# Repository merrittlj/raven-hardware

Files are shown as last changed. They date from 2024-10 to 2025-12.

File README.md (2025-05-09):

<h1 align="center">
    <br>
    Raven - Hardware Repository
    <br>
</h1>
<p align="center">
    
    
    
</p>

## About
This is the hardware repository for the Raven smartwatch. Versioning is completely independent of the firmware repository.

## License

Distributed under the GPLv3. See ['LICENSE'](LICENSE) for more info.

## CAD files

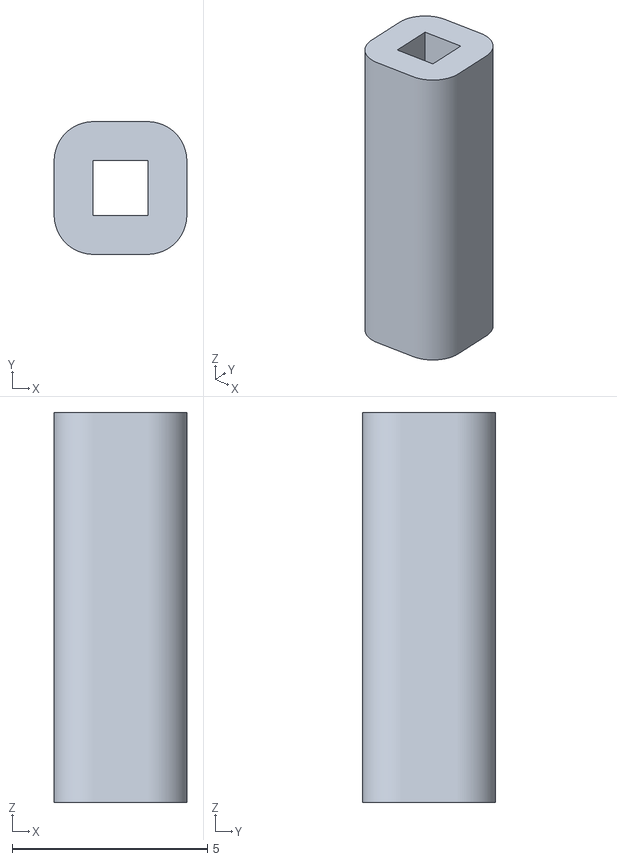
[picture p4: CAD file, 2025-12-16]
case/build.stl
3.40 x 3.40 x 10.0

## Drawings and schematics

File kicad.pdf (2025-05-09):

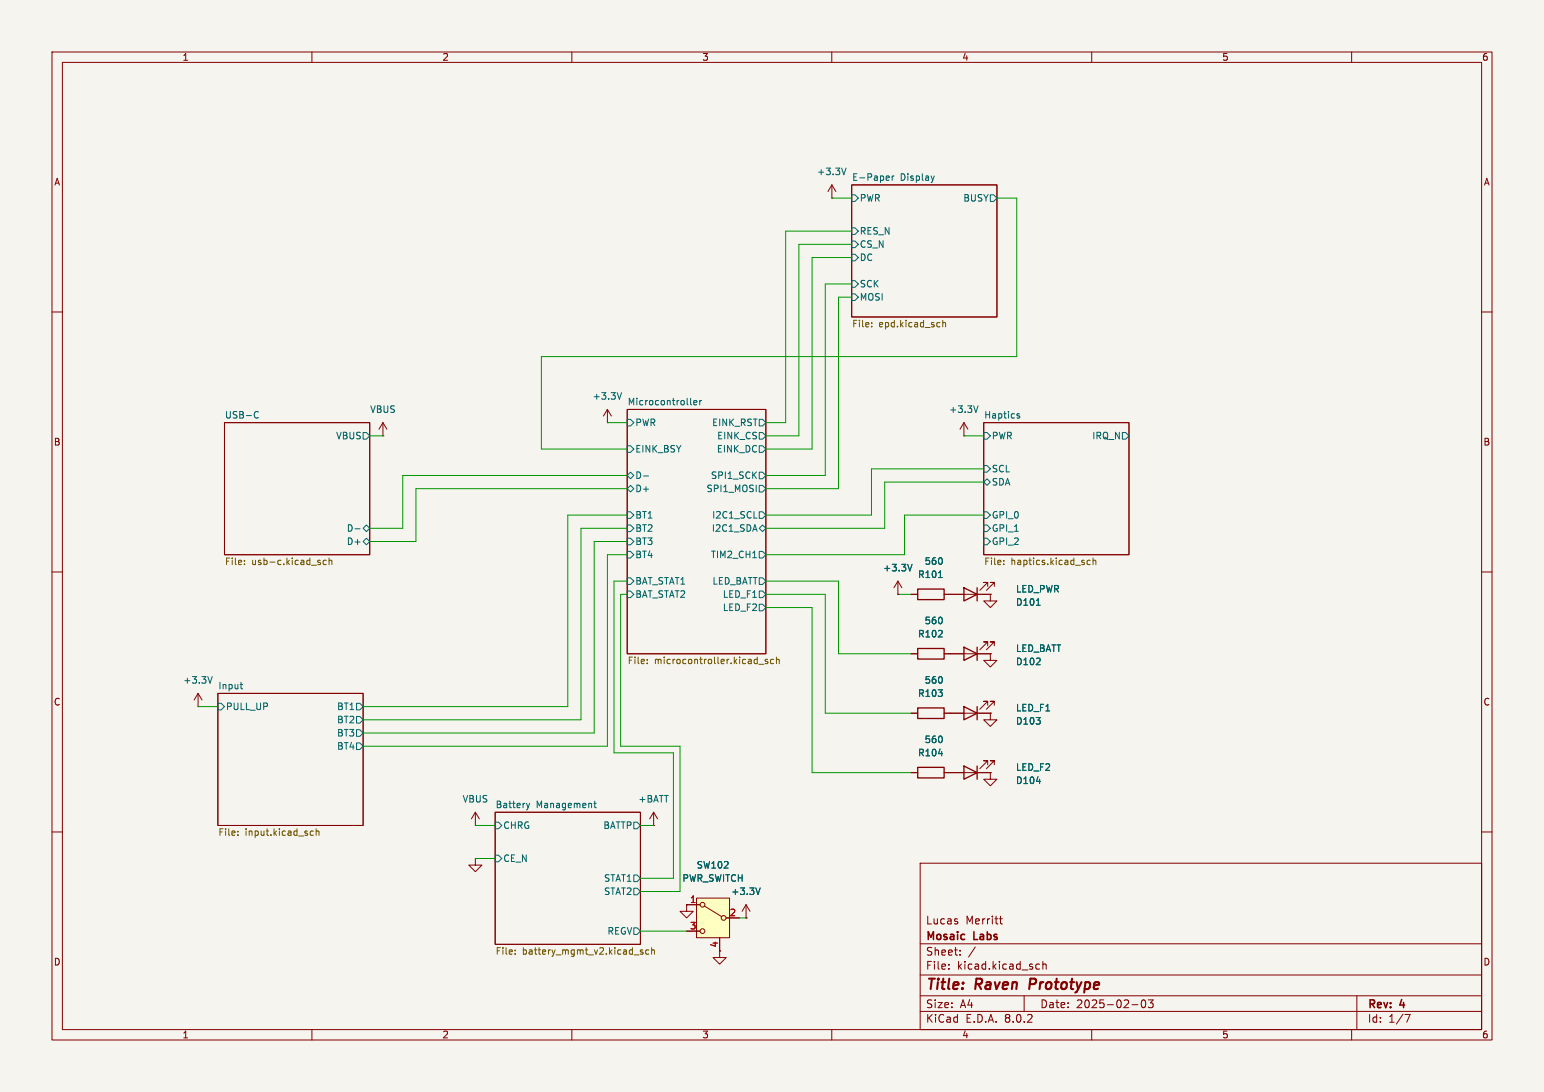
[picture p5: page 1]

SDA Haptics File: haptics.kicad_sch +3.3V

Id: 1/7 Title: Raven Prototype

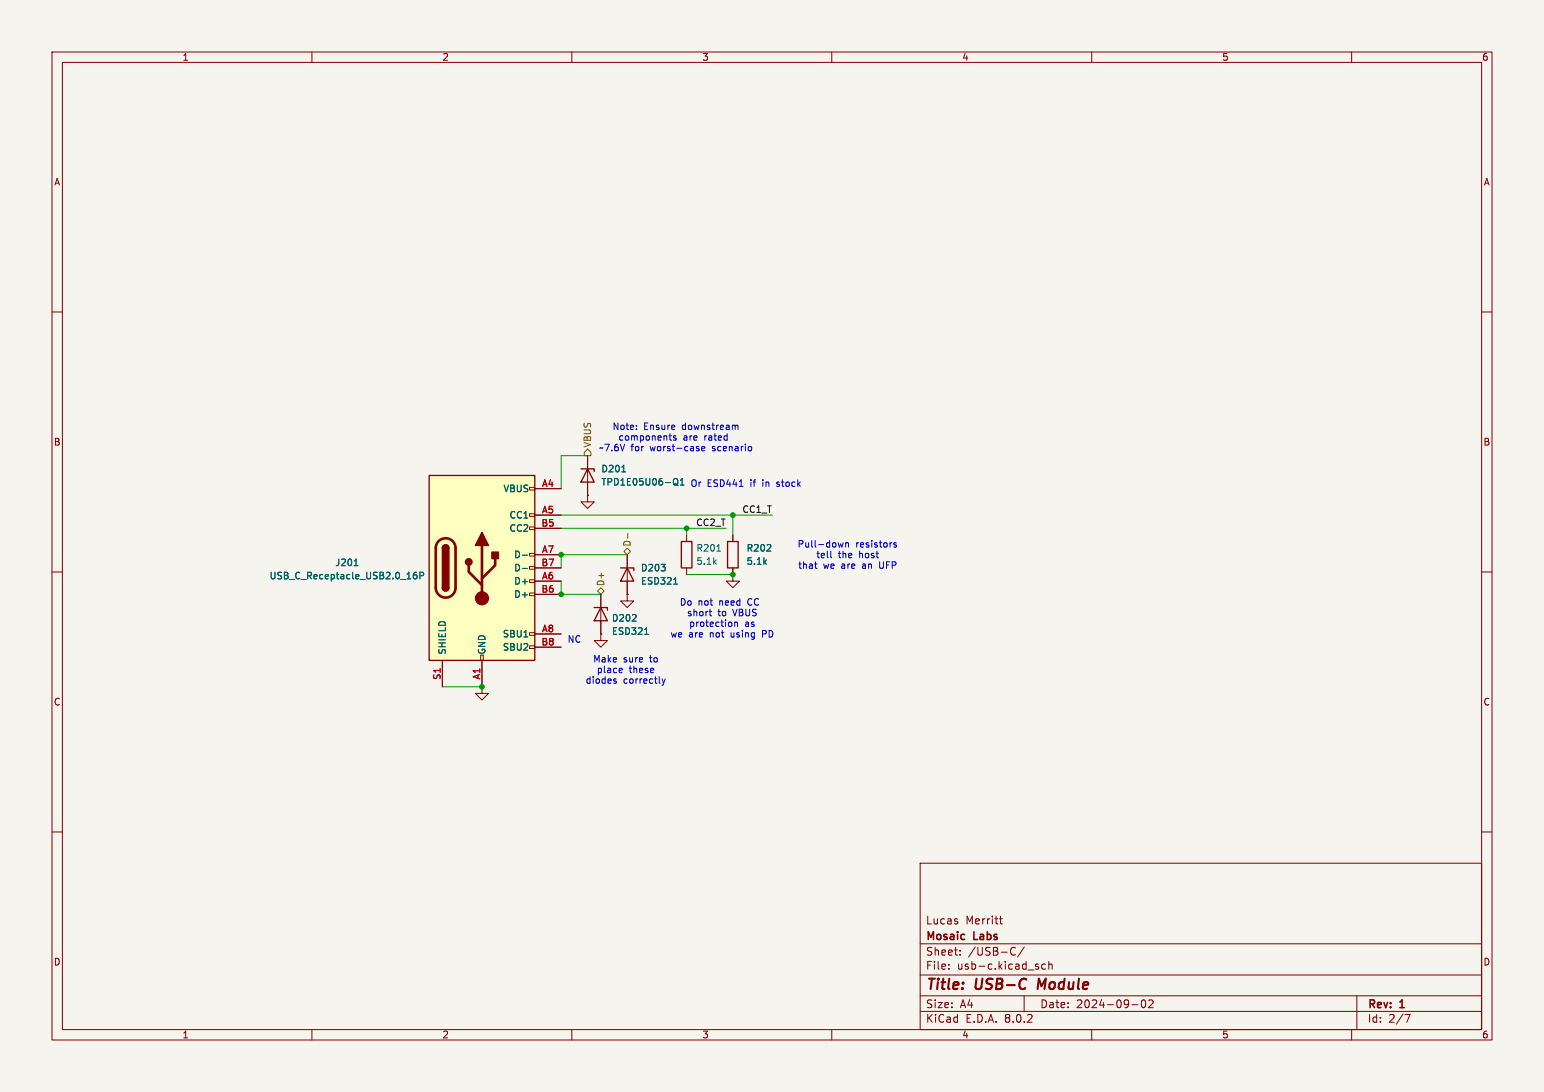
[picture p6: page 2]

Id: 2/7 Title: USB-C Module

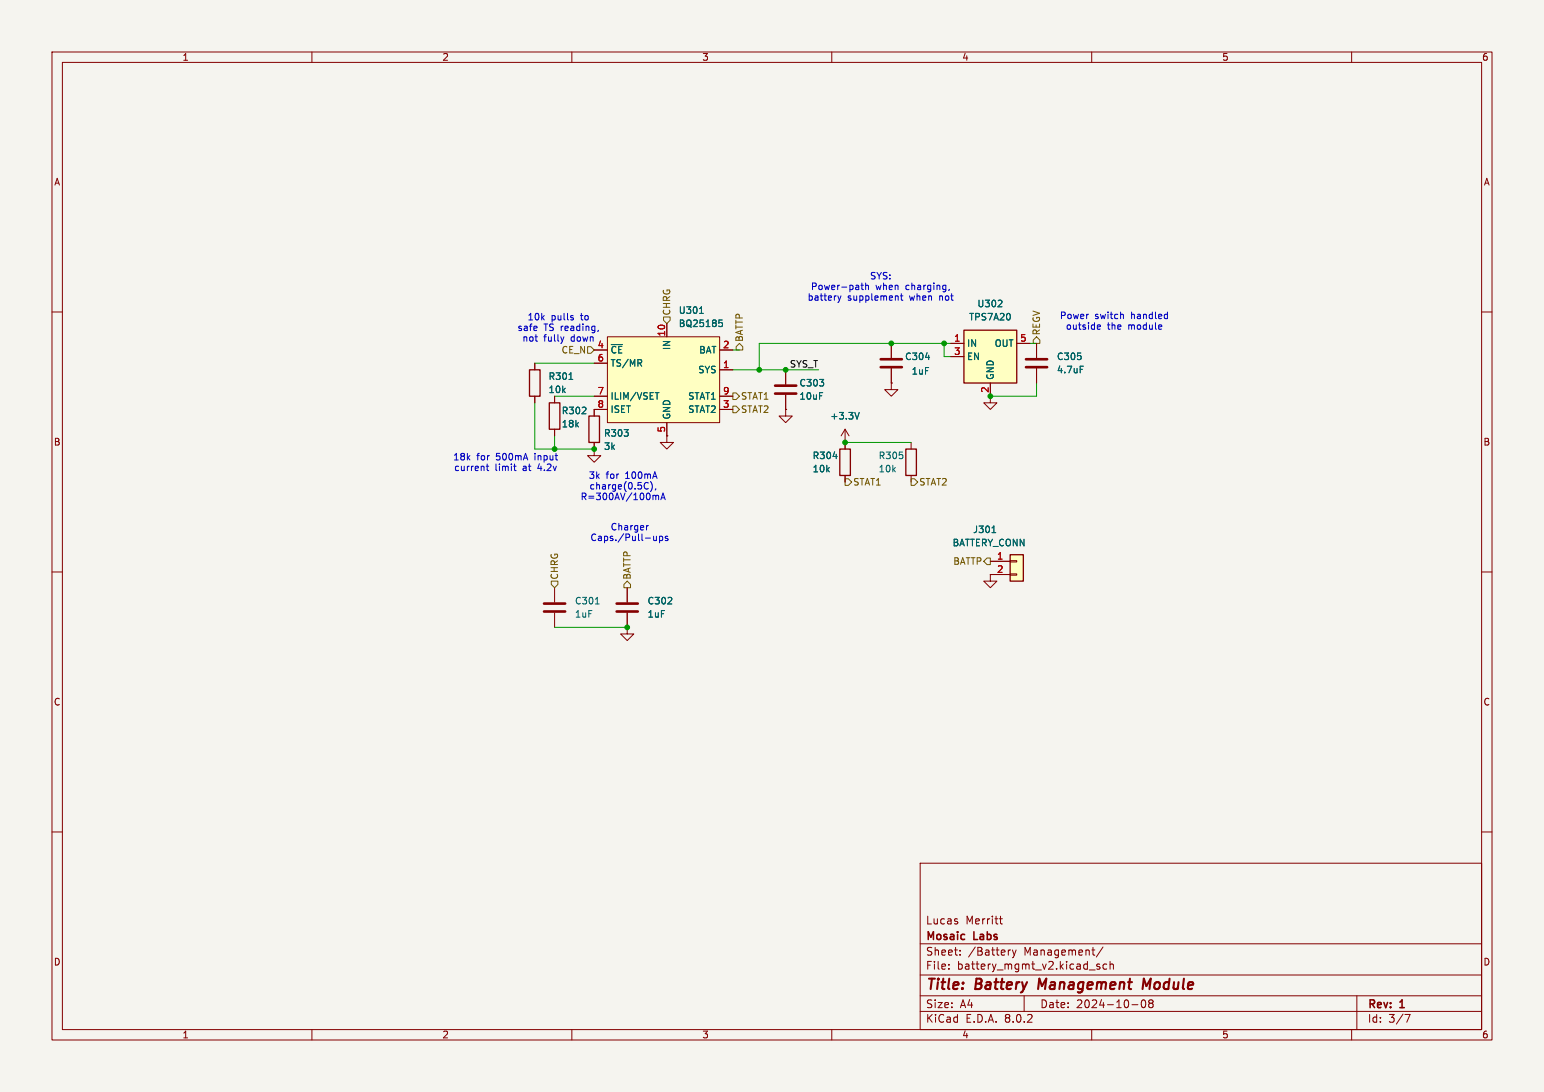
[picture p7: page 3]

2 EN 3 OUT 5 U302 TPS7A20 SYS 1 IN 10 BAT 2 STAT2 3 ~{CE} 4 GND
outside the module Charger

Caps./Pull-ups 3k for 100mA

Id: 3/7 Title: Battery Management Module

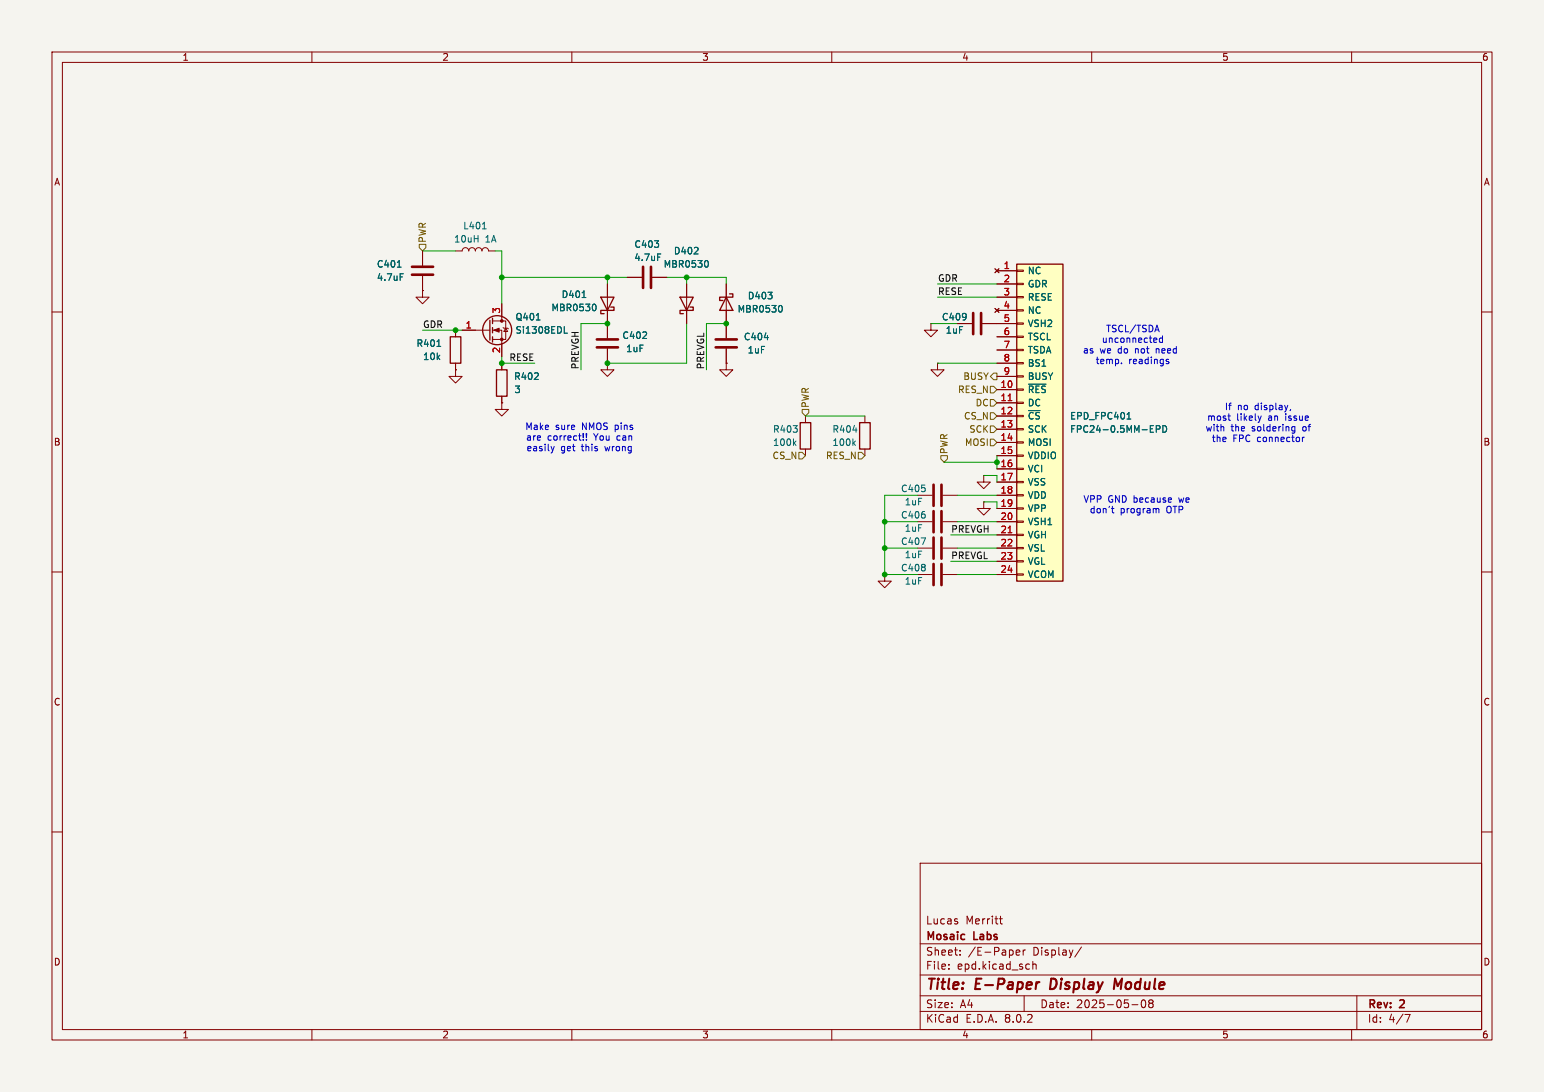
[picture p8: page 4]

easily get this wrong D401 MBR0530 C401

the FPC connector TSCL/TSDA
unconnected
as we do not need

VPP GND because we
don't program OTP

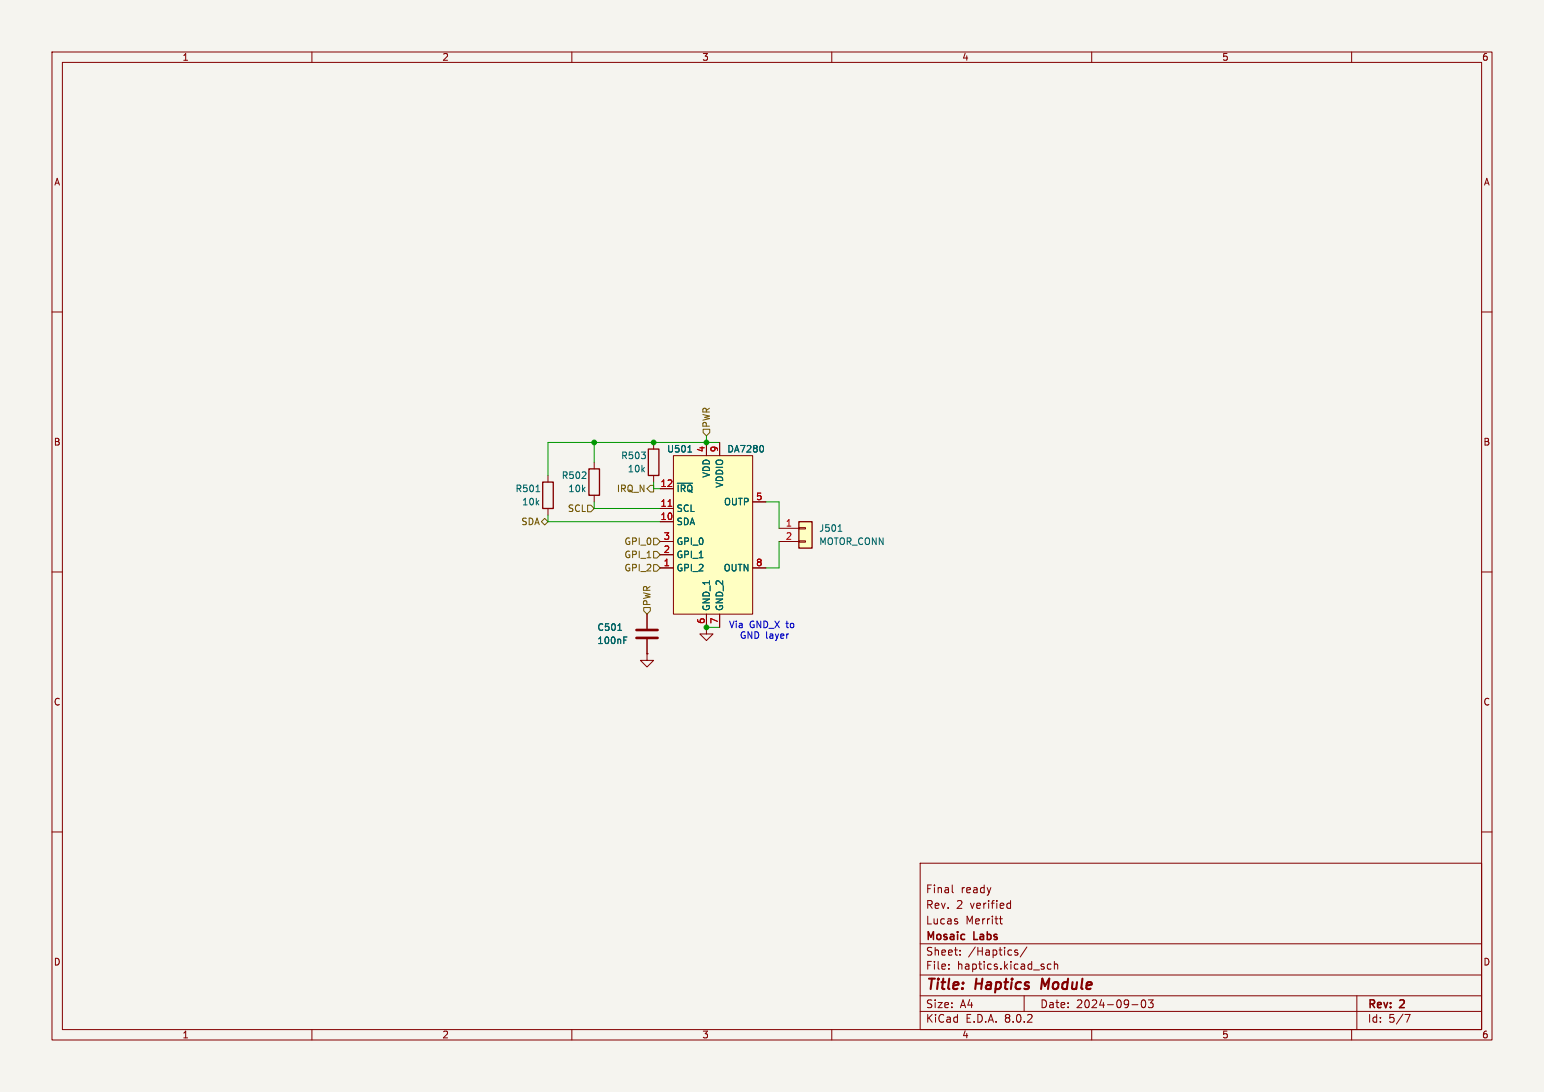
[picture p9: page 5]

Id: 5/7 Title: Haptics Module

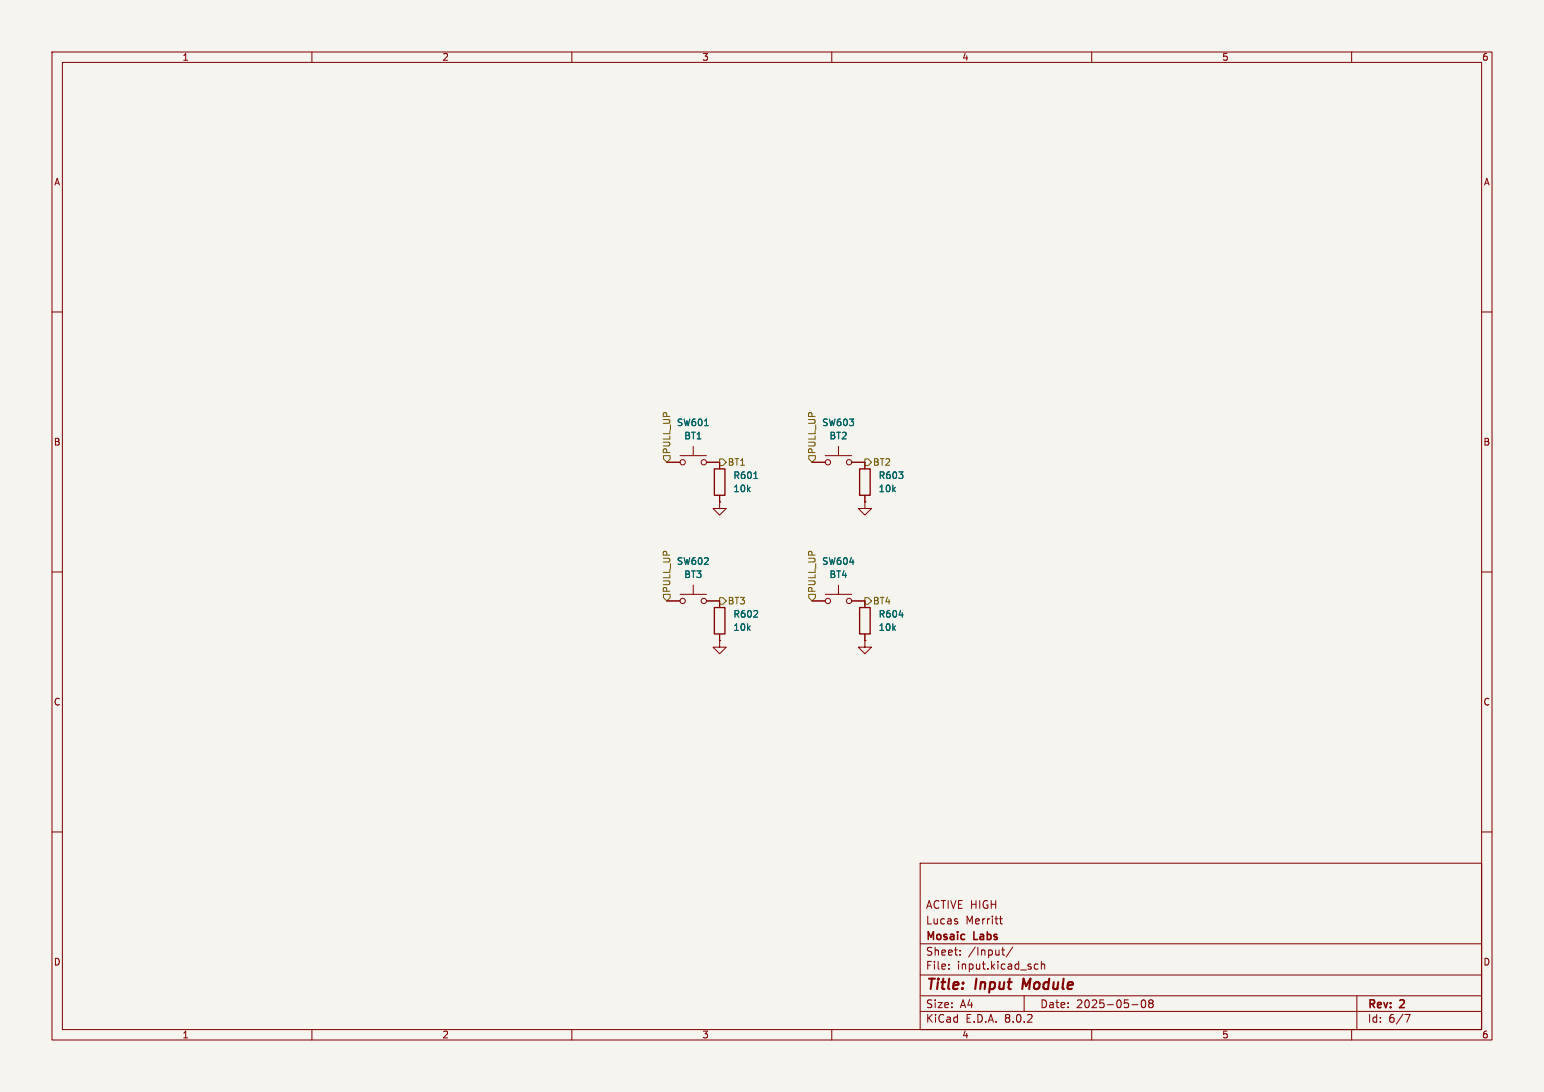
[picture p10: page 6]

Id: 6/7 Title: Input Module

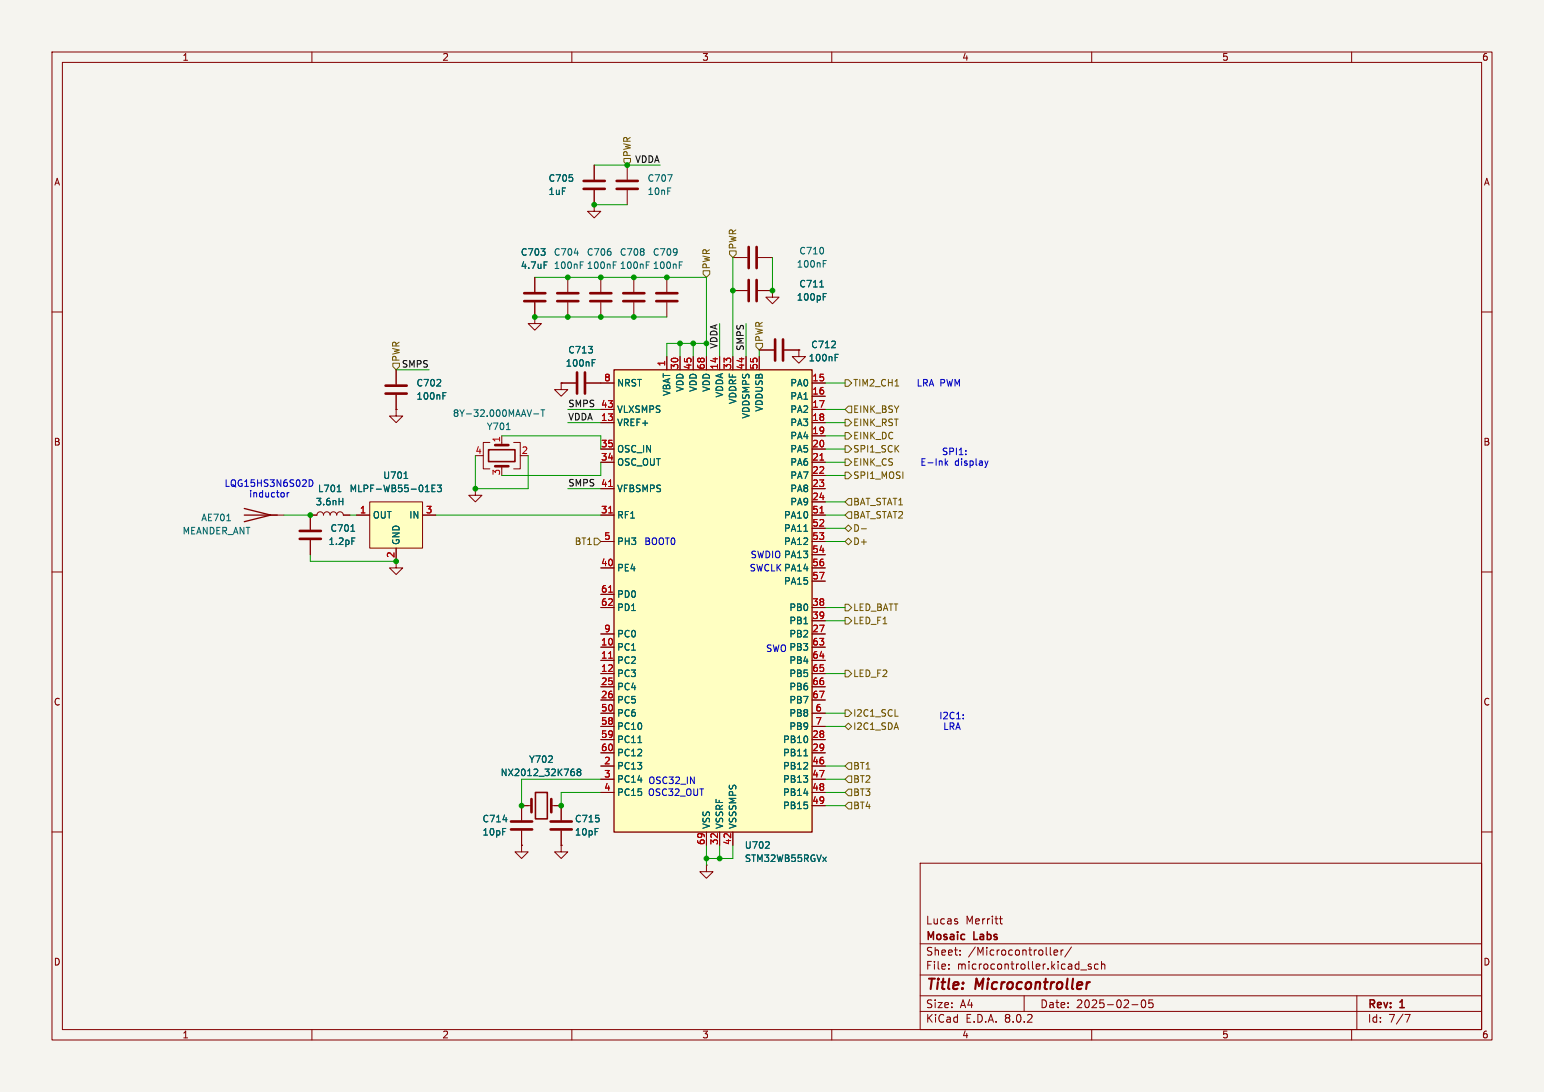
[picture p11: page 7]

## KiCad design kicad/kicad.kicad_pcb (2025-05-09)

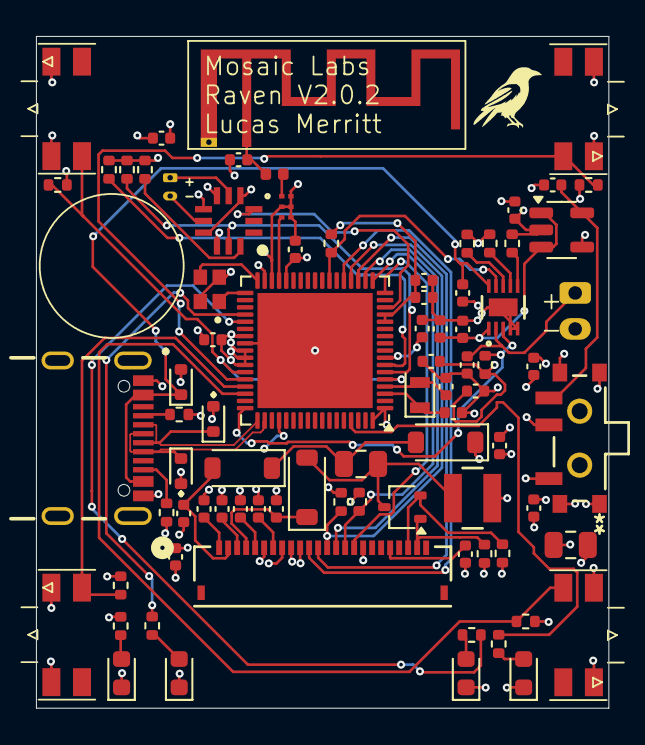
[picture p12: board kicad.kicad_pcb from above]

Board: 4 copper layers, 31.8 x 37.3 mm, 82 parts (0 on the bottom side), 57 nets.

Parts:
AE701: MEANDER_ANT; Texas_SWRA117D_2.4GHz_Right
C301, C302, C304, C402, C404, C405, C406, C407, C408, C409, C705: 1uF; C_0402_1005Metric
C303: 10uF; C_0402_1005Metric
C305, C703: 4.7uF; C_0402_1005Metric
C401, C403: 4.7uF; C_0805_2012Metric
C501, C702, C704, C706, C708, C709, C710, C712, C713: 100nF; C_0402_1005Metric
C701: 1.2pF; C_0402_1005Metric
C707: 10nF; C_0402_1005Metric
C711: 100pF; C_0402_1005Metric
C714, C715: 10pF; C_0402_1005Metric
D101: LED_PWR; D_0603_1608Metric
D102: LED_BATT; D_0603_1608Metric
D103: LED_F1; D_0603_1608Metric
D104: LED_F2; D_0603_1608Metric
D201: TPD1E05U06-Q1; D_SOD-523
D202, D203: ESD321; D_SOD-523
D401, D402, D403: MBR0530; D_SOD-123
EPD_FPC401: FPC24-0.5MM-EPD; CONN_F3311A7H121024E200_AMP_FACE_UP
J201: USB_C_Receptacle_USB2.0_16P; GCT_USB4105-GF-A-16P
J301: BATTERY_CONN; CUSTOM_BATT_CONN
J501: MOTOR_CONN; CUSTOM_MOTOR_CONN
L401: 10uH 1A; IND_BOURNS_SRN3015
L701: 3.6nH; L_0402_1005Metric
Q401: Si1308EDL; SOT-323_SC-70
R101, R102, R103, R104: 560; R_0402_1005Metric
R201, R202: 5.1k; R_0402_1005Metric
R301, R304, R305, R401, R501, R502, R503, R601, R602, R603, R604: 10k; R_0402_1005Metric
R302: 18k; R_0402_1005Metric
R303: 3k; R_0402_1005Metric
R402: 3; R_0402_1005Metric
R403, R404: 100k; R_0402_1005Metric
SW102: PWR_SWITCH; SSSS811101
SW601: BT1; EVQPUA
SW602: BT3; EVQPUA
SW603: BT2; EVQPUA
SW604: BT4; EVQPUA
U301: BQ25185; WSON10_DLH_TEX-M
U302: TPS7A20; SOT-23-5
U501: DA7280; QFN-12-3x3mm-P0.65mm
U701: MLPF-WB55-01E3
U702: STM32WB55RGVx; QFN-68-1EP_8x8mm_P0.4mm_EP6.4x6.4mm
Y701: 8Y-32.000MAAV-T; XTAL_ECS-160-9-37-CKM-TR
Y702: NX2012_32K768; Crystal_SMD_2012-2Pin_2.0x1.2mm

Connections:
+3.3V: C401.1, C501.1, C702.1, C703.1, C704.1, C705.1, C706.1, C707.1, C708.1, C709.1, C710.1, C711.1, C712.2, EPD_FPC401.15 (VDDIO), EPD_FPC401.16 (VCI), L401.2, R101.1, R304.1, R305.1, R403.1, R404.1, R501.1, R502.1, R503.1, SW102.2 (B), SW601.1, SW602.1, SW603.1, SW604.1, U501.4 (VDD), U501.9 (VDDIO), U702.1 (VBAT), U702.13 (VREF+), U702.14 (VDDA), U702.30 (VDD), U702.33 (VDDRF), U702.41 (VFBSMPS), U702.43 (VLXSMPS), U702.44 (VDDSMPS), U702.45 (VDD), U702.55 (VDDUSB), U702.68 (VDD)
+BATT: C302.1, J301.1, U301.2 (BAT)
/Battery Management/REGV: C305.1, SW102.3 (C), U302.5 (OUT)
/Battery Management/STAT1: R304.2, U301.9 (STAT1), U702.24 (PA9)
/Battery Management/STAT2: R305.2, U301.3 (STAT2), U702.51 (PA10)
/Battery Management/SYS_T: C303.1, C304.1, U301.1 (SYS), U302.1 (IN), U302.3 (EN)
/E-Paper Display/BUSY: EPD_FPC401.9 (BUSY), U702.17 (PA2)
/E-Paper Display/CS_N: EPD_FPC401.12 (~CS), R403.2, U702.21 (PA6)
/E-Paper Display/DC: EPD_FPC401.11 (DC), U702.19 (PA4)
/E-Paper Display/GDR: EPD_FPC401.2 (GDR), Q401.1 (G), R401.2
/E-Paper Display/MOSI: EPD_FPC401.14 (MOSI), U702.22 (PA7)
/E-Paper Display/PREVGH: C402.2, D401.1 (K), EPD_FPC401.21 (VGH)
/E-Paper Display/PREVGL: C404.2, D403.2 (A), EPD_FPC401.23 (VGL)
/E-Paper Display/RESE: EPD_FPC401.3 (RESE), Q401.2 (S), R402.1
/E-Paper Display/RES_N: EPD_FPC401.10 (~RES), R404.2, U702.18 (PA3)
/E-Paper Display/SCK: EPD_FPC401.13 (SCK), U702.20 (PA5)
/Haptics/GPI_0: U501.3 (GPI_0), U702.15 (PA0)
/Haptics/IRQ_N: R503.2, U501.12 (~IRQ)
/Haptics/SCL: R502.2, U501.11 (SCL), U702.6 (PB8)
/Haptics/SDA: R501.2, U501.10 (SDA), U702.7 (PB9)
/Input/BT1: R601.1, SW601.2, U702.5 (PH3), U702.46 (PB12)
/Input/BT2: R603.1, SW603.2, U702.47 (PB13)
/Input/BT3: R602.1, SW602.2, U702.48 (PB14)
/Input/BT4: R604.1, SW604.2, U702.49 (PB15)
/Microcontroller/D+: D202.1 (K), J201.A6 (D+), J201.B6 (D+), U702.53 (PA12)
/Microcontroller/D-: D203.1 (K), J201.A7 (D-), J201.B7 (D-), U702.52 (PA11)
/Microcontroller/LED_BATT: R102.1, U702.38 (PB0)
/Microcontroller/LED_F1: R103.1, U702.39 (PB1)
/Microcontroller/LED_F2: R104.1, U702.65 (PB5)
/USB-C/CC1_T: J201.A5 (CC1), R202.1
/USB-C/CC2_T: J201.B5 (CC2), R201.1
GND: C301.2, C302.2, C303.2, C304.2, C305.2, C401.2, C402.1, C404.1, C405.1, C406.1, C407.1, C408.1, C409.1, C501.2, C701.2, C702.2, C703.2, C704.2, C705.2, C706.2, C707.2, C708.2, C709.2, C710.2, C711.2, C712.1, C713.1, C714.2, C715.2, D101.1 (K), D102.1 (K), D103.1 (K), D104.1 (K), D201.2 (A), D202.2 (A), D203.2 (A), D402.1 (K), EPD_FPC401.8 (BS1), EPD_FPC401.17 (VSS), EPD_FPC401.19 (VPP), J201.A1 (GND), J201.A12 (GND), J201.B1 (GND), J201.B12 (GND), J201.S1 (SHIELD), J301.2, R201.2, R202.2, R301.2, R302.2, R303.2, R401.1, R402.2, R601.2, R602.2, R603.2, R604.2, SW102.1 (A), SW102.4, U301.4 (~CE), U301.5 (GND), U301.11 (NC), U302.2 (GND), U302.4 (NC), U501.6 (GND_1), U501.7 (GND_2), U701.2 (GND), U701.4 (GND), U701.5 (GND), U701.6 (GND), U702.32 (VSSRF), U702.42 (VSSSMPS), U702.69 (VSS), Y701.2, Y701.4
unnamed: AE701.1 (A), C701.1, L701.1
unnamed: D101.2 (A), R101.2
unnamed: D102.2 (A), R102.2
unnamed: D103.2 (A), R103.2
unnamed: D104.2 (A), R104.2
unnamed: C403.1, D401.2 (A), L401.1, Q401.3 (D)
unnamed: C403.2, D402.2 (A), D403.1 (K)
unnamed: C408.2, EPD_FPC401.24 (VCOM)
unnamed: C405.2, EPD_FPC401.18 (VDD)
unnamed: C406.2, EPD_FPC401.20 (VSH1)
unnamed: C409.2, EPD_FPC401.5 (VSH2)
unnamed: C407.2, EPD_FPC401.22 (VSL)
unnamed: J501.1, U501.5 (OUTP)
unnamed: J501.2, U501.8 (OUTN)
unnamed: R302.1, U301.7 (ILIM/VSET)
unnamed: R303.1, U301.8 (ISET)
unnamed: R301.1, U301.6 (TS/MR)
unnamed: U701.3 (IN), U702.31 (RF1)
unnamed: L701.2, U701.1 (OUT)
unnamed: C713.2, U702.8 (NRST)
unnamed: U702.35 (OSC_IN), Y701.1
unnamed: U702.34 (OSC_OUT), Y701.3
unnamed: C714.1, U702.3 (PC14), Y702.1
unnamed: C715.1, U702.4 (PC15), Y702.2
VBUS: C301.1, D201.1 (K), J201.A4 (VBUS), J201.A9 (VBUS), J201.B4 (VBUS), J201.B9 (VBUS), U301.10 (IN)

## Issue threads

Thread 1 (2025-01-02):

EPD display not showing anything

merrittlj, 2025-01-02:
This is a complex bug, but it mainly originates from the improper boost converter. The SPI communication seems to be working entirely fine, it just is not getting enough power to actually display the image it wants to.

I believe this originates from the incorrect MOSFET pins, which are fixed in Rev. 2, but I have yet to test this.

merrittlj, 2025-01-10:
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
Wow... Not only does the hacky soldering job work but it was simply the MOSFET...

Closed 2025-01-10.

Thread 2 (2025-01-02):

LEDs way too bright

merrittlj, 2025-01-02:
The LEDs were designed by using the voltages reccomended under the ideal operating conditions on the datasheet, but who ever chose these conditions made them blindingly bright, we need to add much larger resistors.

Resistors in the 1-3k range seem to work nice.

merrittlj, 2025-01-10:
Completed by d8ea87978131bd46c603eb13500808e90a7d5579

Closed 2025-01-10.

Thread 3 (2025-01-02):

FPC connector issues

merrittlj, 2025-01-02:
The FPC connector(https://www.digikey.com/short/9n5nj2th) is currently out of stock and slightly problematic. The FPC cable does not fully go in to a satisfying/assuring degree, but as long as the display circuit is properly verified this might be fine. Additionally, we do not need connections on both sides of the connector.

merrittlj, 2025-01-10:
Display is verified, FPC works fine, but still need to switch out connector(maybe? there are some equivalents).

merrittlj, 2025-01-10:
Completed by d8ea87978131bd46c603eb13500808e90a7d5579

Closed 2025-01-10.

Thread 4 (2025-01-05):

Power on and off management

merrittlj, 2025-01-05:
How should the hardware handle powering the device on and off? Is such a feature necessary, what is the complexity of doing such, etc.

merrittlj, 2025-02-07:
This was completed a while ago with the addition of a physical power switch.

Closed 2025-02-07.

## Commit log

2024-08-16 start adding connectors
    [kicad.kicad_pcb, kicad.kicad_sch]
2024-08-17 connect all fpc connector pins
    [kicad.kicad_sch]
2024-08-17 first boost converter revision
    [kicad.kicad_sch]
2024-08-18 schem v1
    [kicad.kicad_sch]
2024-08-22 add debugging to v1
    [kicad.kicad_sch]
2024-08-23 add DA7280 symbol, rename to raven, organize schem
    [kicad.kicad_sch]
2024-08-24 reorganize schematic, add haptic, debug, connector module
    [kicad.kicad_sch]
2024-08-25 start power circuit
    [kicad.kicad_sch]
2024-08-25 power IC work
    [kicad.kicad_sch]
2024-08-26 reorganize, start usb-c
    [kicad.kicad_sch]
2024-08-28 start usb-c symbols
    [kicad.kicad_sch]
2024-08-28 finish usb esd symbol
    [kicad.kicad_sch]
2024-08-29 power close to completion
    [kicad.kicad_sch]
2024-08-31 add BQ21061
    [kicad.kicad_sch, power_supply.kicad_sch]
2024-09-03 modularize usb-c
    [kicad.kicad_sch, usb-c.kicad_sch, usbc_power.kicad_sch]
2024-09-04 add datasheets, modularize current hardware
    [battery_management.kicad_sch, battery_mgmt.kicad_sch, epd.kicad_sch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]
2024-09-10 add power v2, input, storage modules
    [battery_mgmt_v1.kicad_sch, battery_mgmt_v2.kicad_sch, input.kicad_sch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]
2024-09-11 refactor, fix issues, ready for first design
    [battery_management.kicad_sch, battery_mgmt.kicad_sch, battery_mgmt_v2.kicad_sch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]
2024-09-19 sync, almost done
    [kicad.kicad_sch]
2024-09-28 schematic should be finished
    [battery_mgmt_v2.kicad_sch, epd.kicad_sch, input.kicad_sch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]
2024-09-30 essentially finish schematic, start adding footprints, add new footprints
    [battery_mgmt_v2.kicad_sch, epd.kicad_sch, haptics.kicad_sch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]
2024-09-30 add button orientation and clearance
    [input.kicad_sch]
2024-10-01 fix motor with spring fingers, start PCB
    [battery_mgmt_v2.kicad_sch, epd.kicad_sch, haptics.kicad_sch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]
2024-10-01 fix errors/update USB-c footprint, DA7280 footprint still needs fixing
    [epd.kicad_sch, haptics.kicad_sch, input.kicad_sch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]
2024-10-02 PCB almost finished: only battery & usb-c needed
    [epd.kicad_sch, haptics.kicad_sch, kicad.kicad_pcb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]
2024-10-04 finish PCB routing, need silkscreen + checks
    [battery_mgmt_v2.kicad_sch, kicad.kicad_pcb, kicad.kicad_sch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]
2024-10-04 fix and place silkscreen
    [kicad.kicad_pcb]
2024-10-04 silkscreen art!
    [kicad.kicad_pcb]
2024-10-05 refactor usb-c module, remove unnecessary ICs
    [kicad.kicad_pcb, kicad.kicad_sch, usb-c.kicad_sch]
2024-10-05 finish pcb v1.0.0
    [kicad.kicad_pcb]
2024-10-06 minor fixes, generate fab files
    [kicad-B_Cu.gbl, kicad-B_Mask.gbs, kicad-B_Paste.gbp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]
2024-10-07 add some assembly files, but transition towards all hand
    [battery_mgmt_v2.kicad_sch, epd.kicad_sch, haptics.kicad_sch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]
2024-10-08 add BQ25185 symbol, start battery design with it
    [battery_mgmt_v2.kicad_sch]
2024-10-09 new battery management w/ separate LDO/charger almost done
    [battery_mgmt_v2.kicad_sch, epd.kicad_sch, haptics.kicad_sch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]
2024-10-09 slight refactoring, fix LDO power-path
    [battery_mgmt_v1.kicad_sch, battery_mgmt_v2.kicad_sch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]
2024-10-09 finish management schematic, ready for PCB
    [battery_mgmt_v2.kicad_sch, epd.kicad_sch, kicad.kicad_sch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]
2024-10-09 finish battery PCB layout, PCB refactoring
    [battery_mgmt_v2.kicad_sch, epd.kicad_sch, kicad.kicad_pcb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]
2024-10-10 official hardware version v1.0.0, generate gerbers
    [kicad-B_Cu.gbl, kicad-B_Mask.gbs, kicad-B_Paste.gbp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]
2024-10-10 add LICENSE, open source
    [kicad-B_Cu.gbl, kicad-B_Mask.gbs, kicad-B_Paste.gbp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]
2024-12-31 Revision 2: Fix MOSFET pins and various changes
    [battery_mgmt_v2.kicad_sch, epd.kicad_sch, input.kicad_sch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]
2025-01-10 Rev. 3: Fix issues
    [epd.kicad_sch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]
2025-01-16 Minor revisions for haptics and PCB
    [epd.kicad_sch, haptics.kicad_sch, input.kicad_sch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]
2025-01-27 start microcontroller schematic
    [kicad.kicad_sch, microcontroller.kicad_sch]
2025-01-27 Start removing debug and integrate microcontroller
    [kicad.kicad_sch, microcontroller.kicad_sch]
2025-01-28 Microcontroller additions
    [epd.kicad_sch, haptics.kicad_sch, input.kicad_sch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]
2025-02-03 Unfinished switch additions and fixes
    [battery_mgmt_v2.kicad_sch, epd.kicad_sch, haptics.kicad_sch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]
2025-02-03 Small switch updates and fixes
    [epd.kicad_sch, input.kicad_sch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]
2025-02-05 Part updates
    [battery_mgmt_v2.kicad_sch, haptics.kicad_sch, kicad.kicad_sch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]
2025-02-05 Finish microcontroller power supply
    [kicad.kicad_sch, microcontroller.kicad_sch]
2025-02-05 Microcontroller XTAL, BMS, and Flashing connections
    [microcontroller.kicad_sch]
2025-02-05 Finish microcontroller, adding RF
    [microcontroller.kicad_sch]
2025-02-05 Footprint and MC updates
    [input.kicad_sch, microcontroller.kicad_sch]
2025-02-06 Begin PCB, update footprints
    [battery_mgmt_v2.kicad_sch, epd.kicad_sch, haptics.kicad_sch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]
2025-02-07 PCB progress
    [battery_mgmt_v2.kicad_sch, kicad.kicad_pcb, kicad.kicad_sch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]
2025-02-07 Finish PCB component placement
    [battery_mgmt_v2.kicad_sch, haptics.kicad_sch, kicad.kicad_pcb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]
2025-02-07 PCB Trace progress
    [kicad.kicad_pcb, kicad.kicad_sch, microcontroller.kicad_sch]
2025-02-07 Minor schematic fixes and PCB trace progress
    [battery_mgmt_v2.kicad_sch, kicad.kicad_pcb, kicad.kicad_sch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]
2025-02-08 Minor changess
    [kicad.kicad_pcb]
2025-02-10 Update PCB for better routing of RF, USB-C, and through backside
    [epd.kicad_sch, kicad.kicad_pcb]
2025-02-10 Add power/gnd vias
    [kicad.kicad_pcb]
2025-02-11 Fix bad connections
    [kicad.kicad_pcb]
2025-02-12 Begin EPD redo
    [epd.kicad_sch, kicad.kicad_pcb]
2025-02-13 Finish flipping EPD
    [kicad.kicad_pcb]
2025-02-18 Fix DRC errors and vias
    [kicad.kicad_pcb]
2025-02-18 Finish silkscreen
    [battery_mgmt_v2.kicad_sch, kicad.kicad_pcb]
2025-03-03 Update BOOT0
    [kicad.kicad_pcb, microcontroller.kicad_sch]
2025-03-06 Fix V2.0.0 files
    [kicad-B_Cu.gbl, kicad-B_Mask.gbs, kicad-B_Paste.gbp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]
2025-03-07 Fix tiny vias, update gerber
    [kicad-B_Cu.gbl, kicad-B_Mask.gbs, kicad-B_Paste.gbp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]
2025-03-07 Actually fix gerber.zip now
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2025-10-08 case revision 1
    [case.stl]
2025-10-09 case revision 2
    [case.stl]
2025-10-09 case revision 3
    [case.stl]
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2025-10-13 wip switch to build123d
    [build.stl]
2025-10-14 build123d wip
    [build.stl]
2025-10-14 full build123d migration + holder additions
    [build.stl, case.stl]
2025-10-16 add caps and bottom
    [build.stl]
2025-10-20 print v4
    [build.stl]
2025-10-21 print rev 5
    [build.stl]
2025-12-15 rev 6
    [build.stl]
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2025-12-16 new back + power cap
    [build.stl]
